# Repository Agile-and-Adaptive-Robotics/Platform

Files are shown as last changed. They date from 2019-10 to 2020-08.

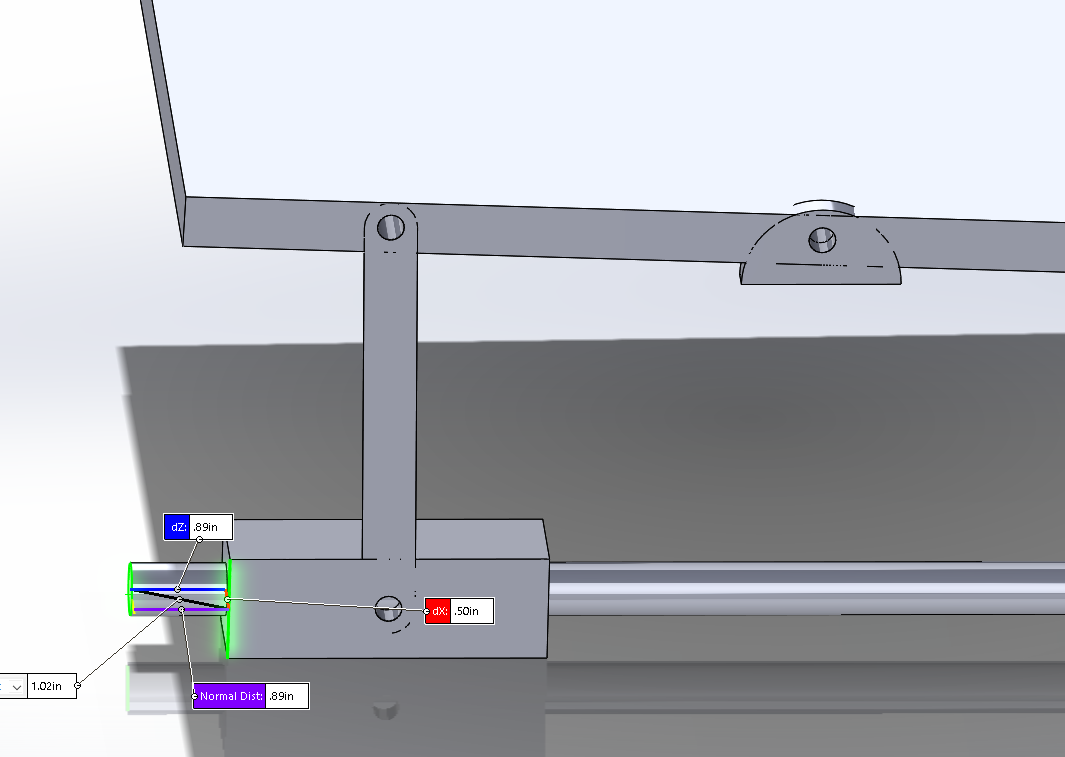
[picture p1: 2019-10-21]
Linsey_s Documentation/screenshots/Works_1redo.PNG

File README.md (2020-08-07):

# Platform

This repo is for the Platform project to test the Bipedal robot in the Agile Adaptive Robotics Lab

Platform

## Content

Goals: To create a balance platform that can vibrate at pseudorandom pattern to test the Bipedal robot. 
Dr. Hunt wants the platform to be able to generate a motion following the pseudo random ternary sequence to test the bipedal robot. When the robot is tested on this platform, the transfer function of the bipedal robot can be derived. 

## Deadline:
At least the end of Spring Term 2020 
Due to the pandemic, this deadline has been missed. Currently, there is no deadline.

## Creators:

Original Designer: Lindsey

2nd Designer: Connor Morrow

3rd Designer: Jake Chung

## Parts List:
- LM 7805C - Voltage regulator 
- LM 348N - Quad op-amp
- MCP 4921 - DAC
- Syren 50 - H-Bridge

## Notes:

Link to the DC motor: https://www.robotmarketplace.com/products/0-e30-150.html

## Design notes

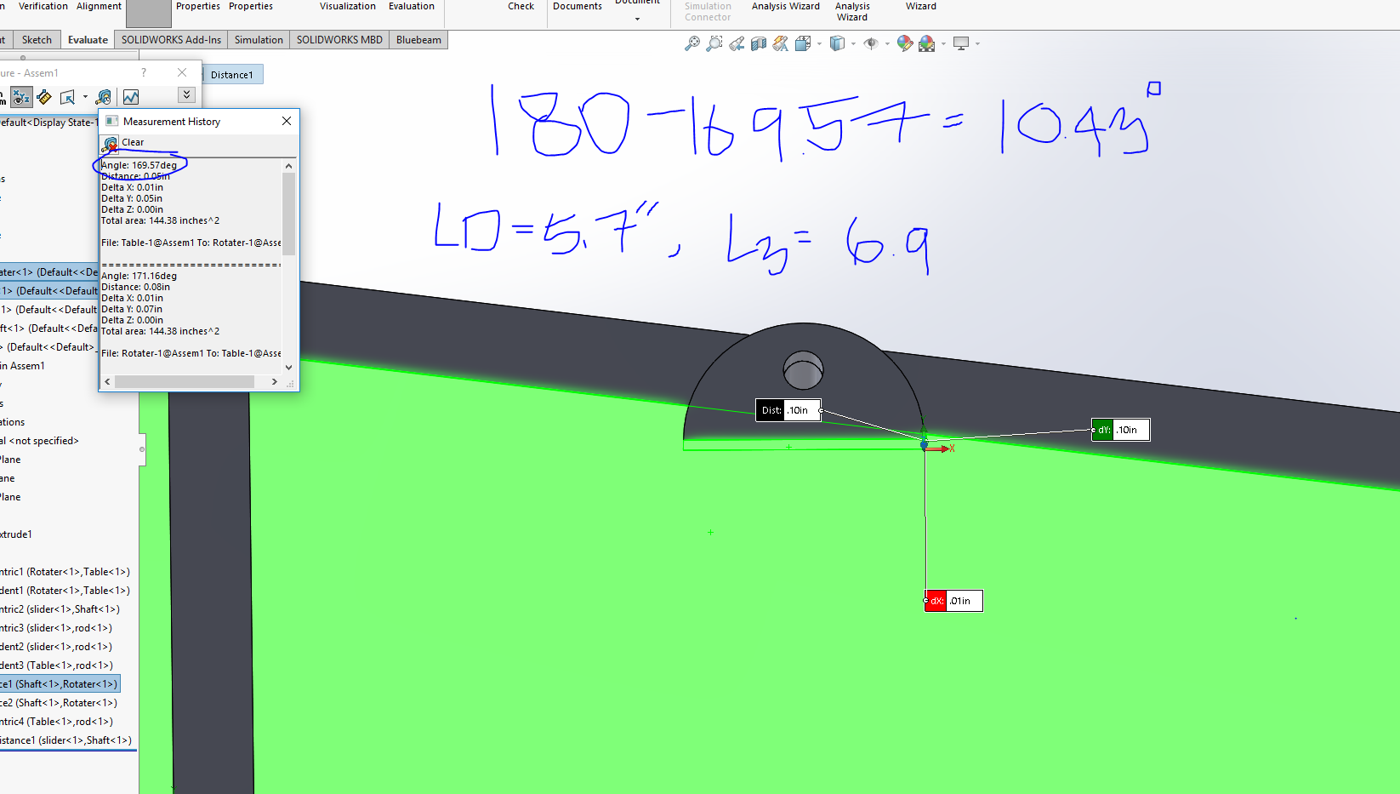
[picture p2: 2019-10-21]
Linsey_s Documentation/screenshots/T3_angle-042218.PNG

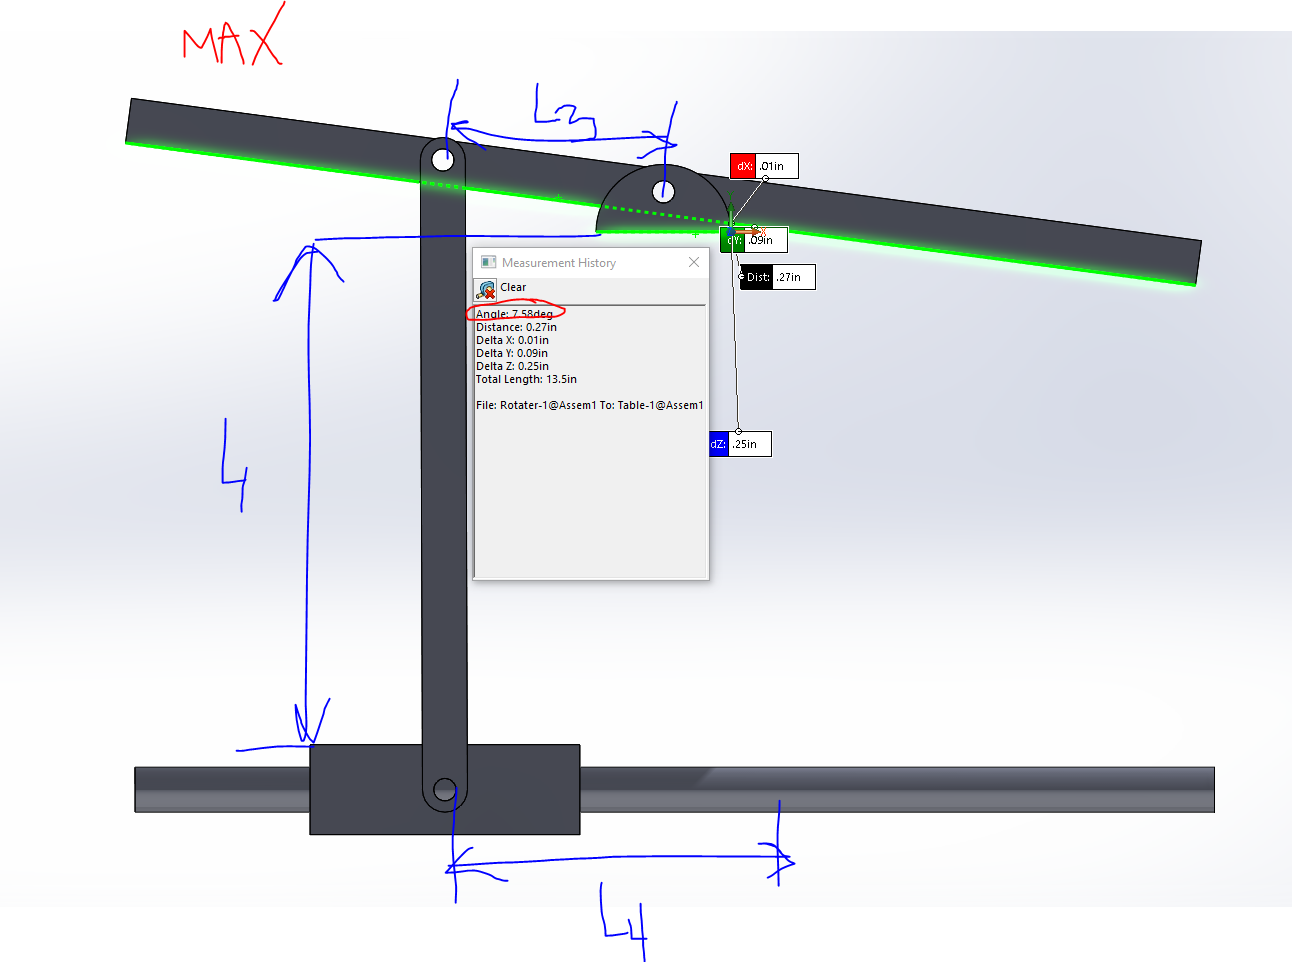
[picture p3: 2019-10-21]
Linsey_s Documentation/screenshots/tech.PNG

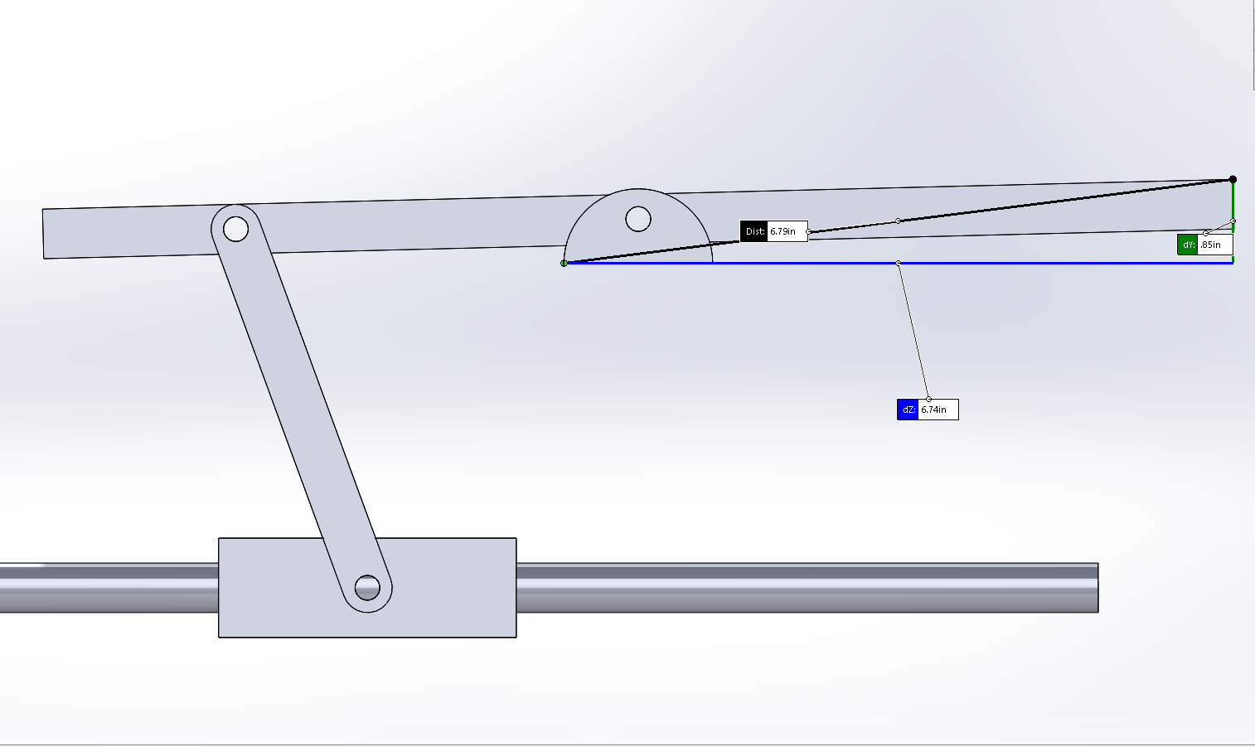
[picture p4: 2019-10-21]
Linsey_s Documentation/screenshots/Works_1_right.PNG

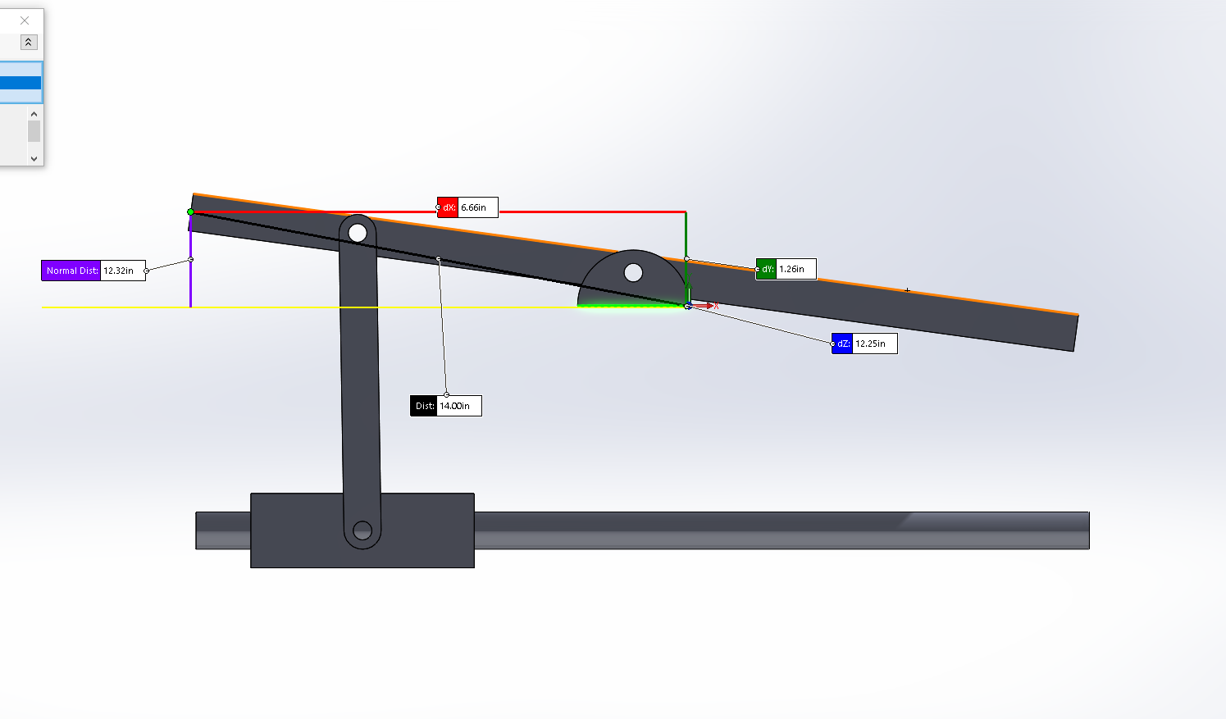
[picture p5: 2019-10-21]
Linsey_s Documentation/screenshots/10 degrees.PNG

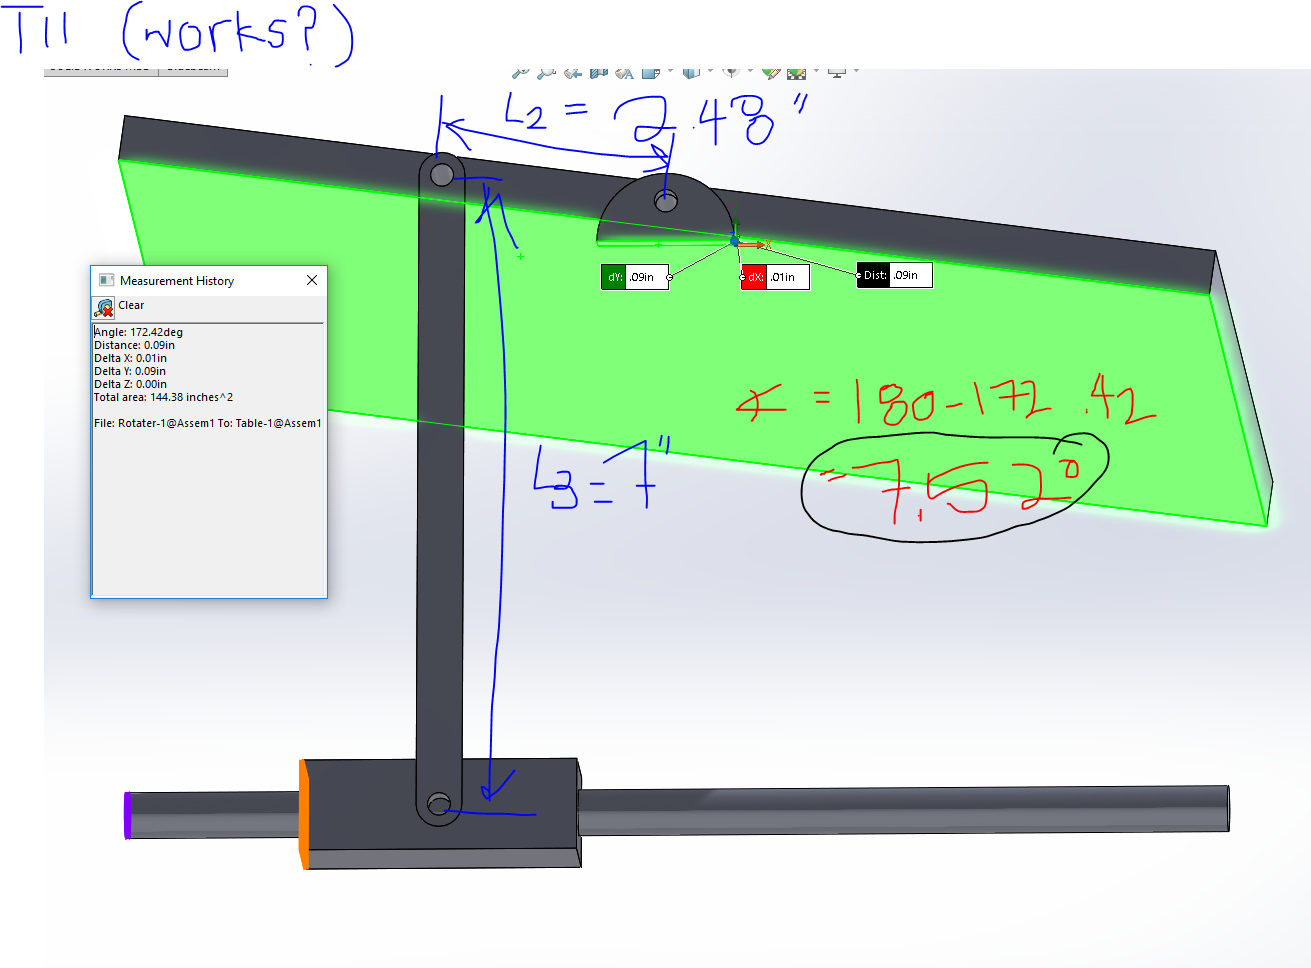
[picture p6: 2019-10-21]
Linsey_s Documentation/screenshots/T11_angle-042418.PNG

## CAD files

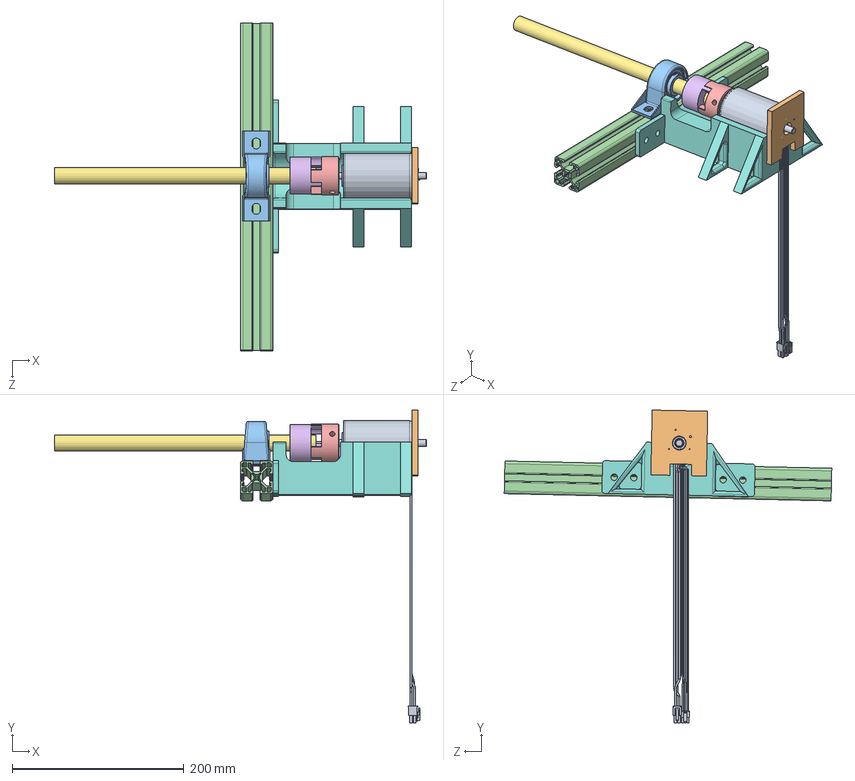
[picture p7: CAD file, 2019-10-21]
Linsey_s Documentation/Solidworks in use/model ideas/mini.SLDASM
433.5 x 364.6 x 381.8 mm
maxon
plate_w_hole
bigrot
8.00004_coup
0.75 coup
no revolve cut shaft
motorsupport

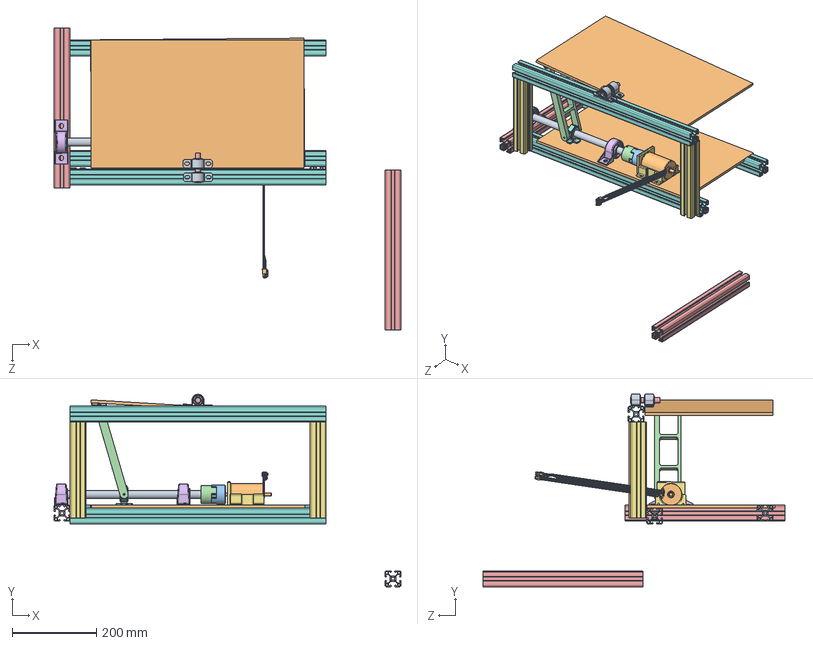
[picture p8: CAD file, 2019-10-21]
Linsey_s Documentation/Solidworks in use/model ideas/PlatBod_other.SLDASM
826.2 x 458.4 x 720.2 mm
rotty x 2
board x 2
tiny_bear x 2
rod2
baby_shaft
bigrot
no revolve cut shaft
maxon
8.005_coup
9939T204_ZERO-BACKLASH FLEXIBLE SHAFT COUPLING
5913K630_LOW-PROFILE MOUNTED BALL BEARING
cradle2
bolt_backpack2
98948A750_GENERAL PURPOSE ACME HEX NUT

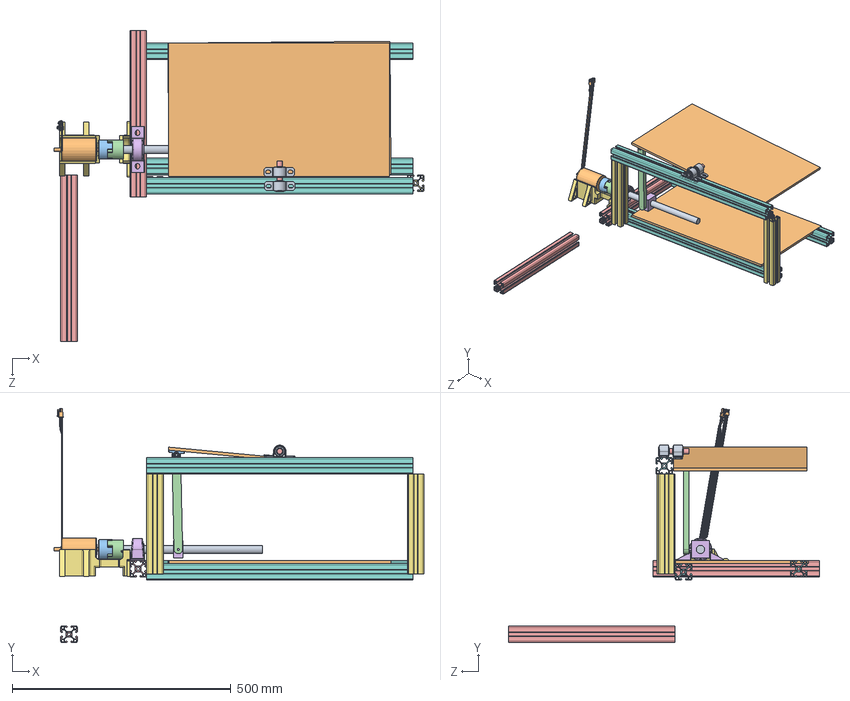
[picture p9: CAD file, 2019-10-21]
Linsey_s Documentation/Solidworks in use/model ideas/PlatBod.SLDASM
846.1 x 535.6 x 711.2 mm
rotty x 2
board x 2
tiny_bear
rod
baby_shaft
bigrot
no revolve cut shaft
maxon
8.005_coup
9939T204_ZERO-BACKLASH FLEXIBLE SHAFT COUPLING
fake_block
motorsupport - Copy2

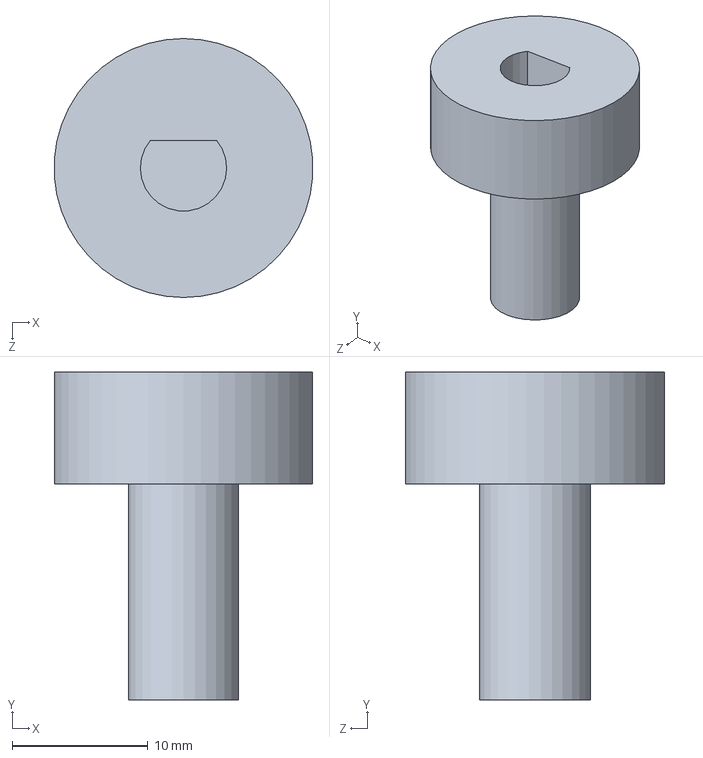
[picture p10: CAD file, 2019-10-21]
Linsey_s Documentation/Solidworks in use/jacks_adaptv2.SLDPRT
19.0 x 24.1 x 19.1 mm

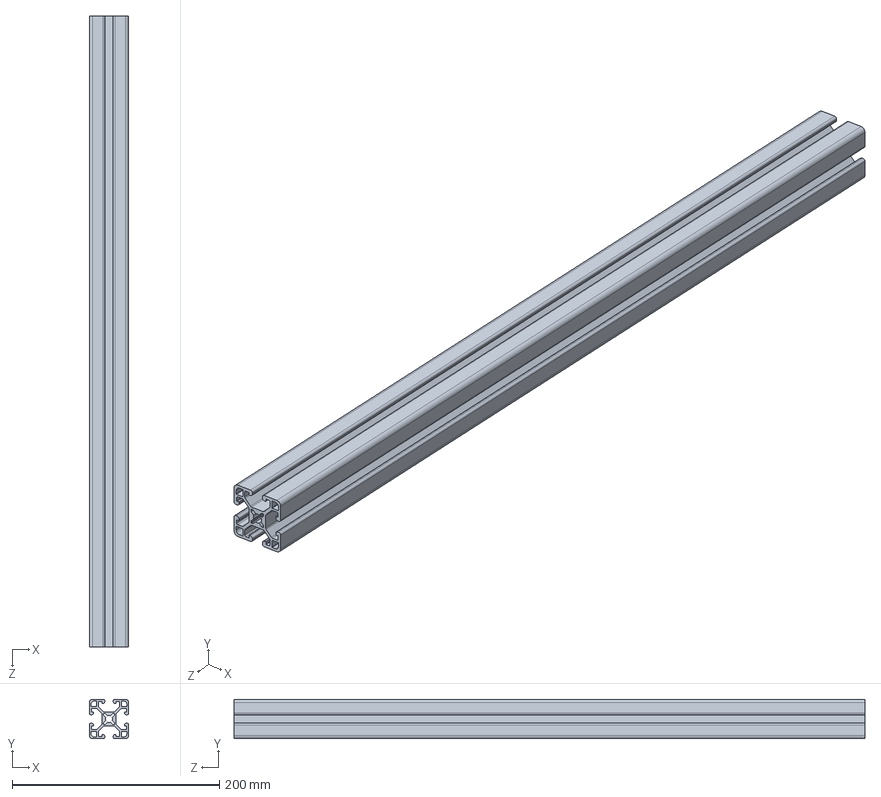
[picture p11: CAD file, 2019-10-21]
Linsey_s Documentation/Solidworks in use/not 3dprinted stuff/1515_24.SLDPRT
38.1 x 38.1 x 609.6 mm

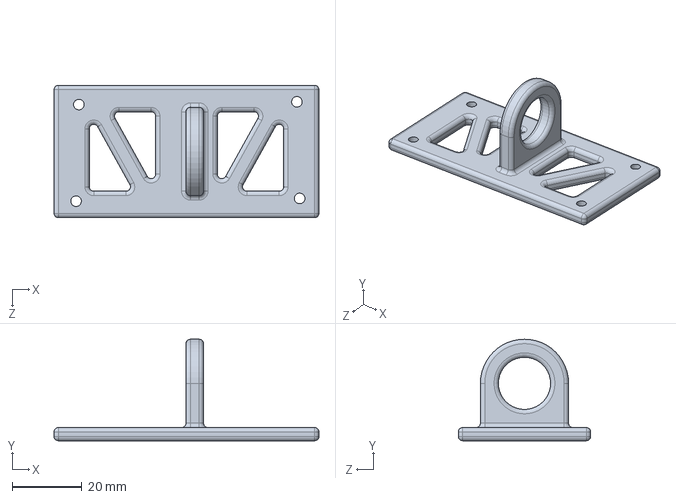
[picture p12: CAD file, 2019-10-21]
Solidworks Files/BP_Platform_Linkage_Connection_1.SLDPRT
76.2 x 29.2 x 38.1 mm

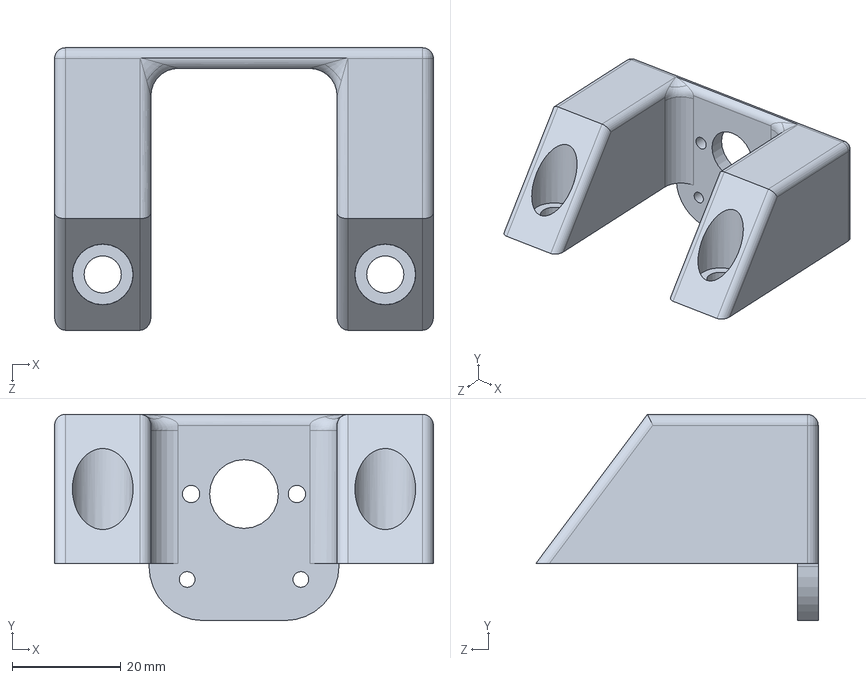
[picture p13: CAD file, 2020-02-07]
Solidworks Files/jakesDesign/BP_encodeHolder.SLDPRT
69.8 x 38.0 x 52.1 mm

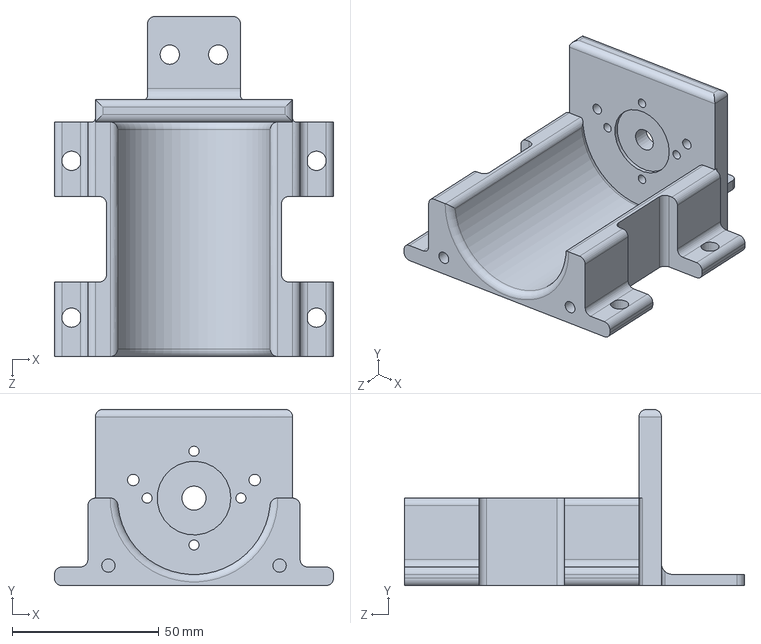
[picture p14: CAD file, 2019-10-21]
Linsey_s Documentation/Solidworks in use/cradle2.SLDPRT
95.2 x 60.1 x 116.0 mm

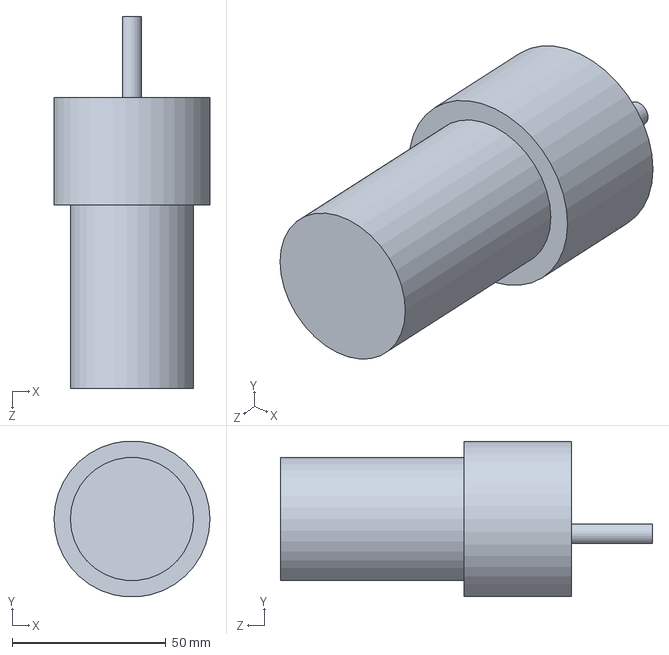
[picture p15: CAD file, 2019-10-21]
Linsey_s Documentation/Solidworks in use/not 3dprinted stuff/mechatronics_motor.SLDPRT
50.8 x 50.6 x 121.2 mm

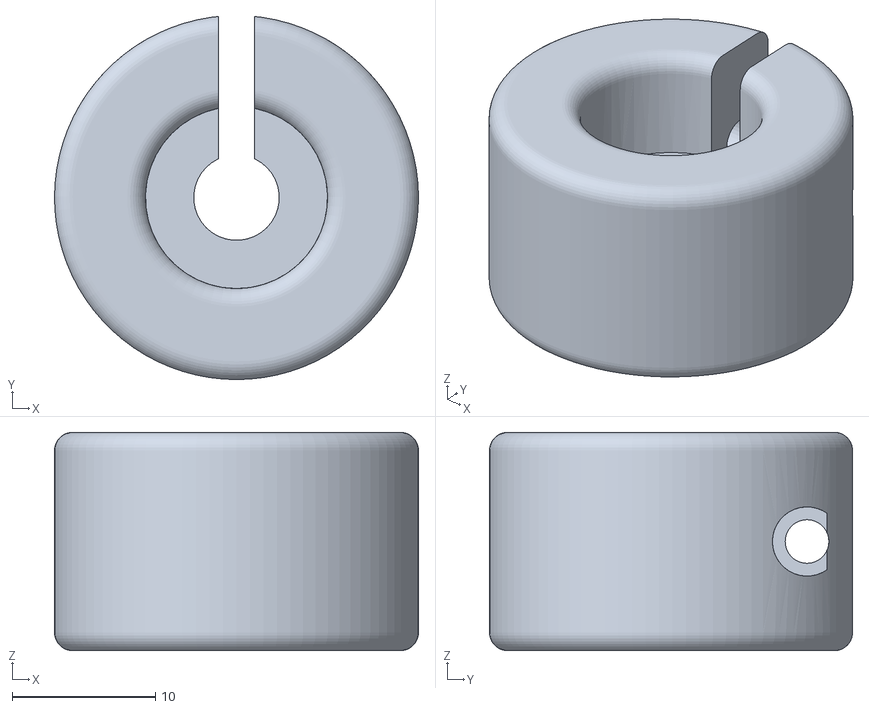
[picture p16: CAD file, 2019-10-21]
Solidworks Files/BP_Pot_Shaft_Interface_2.STL
25.4 x 25.3 x 15.2

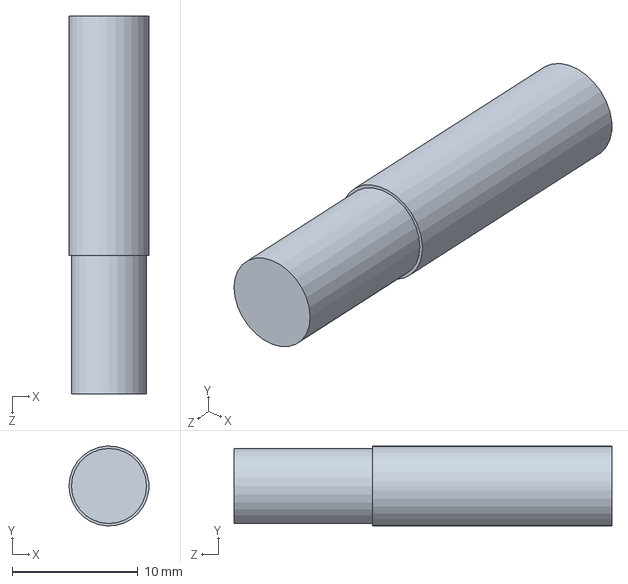
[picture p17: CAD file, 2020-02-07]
Solidworks Files/jakesDesign/encoderShaft.SLDPRT
6.35 x 6.34 x 30.0 mm

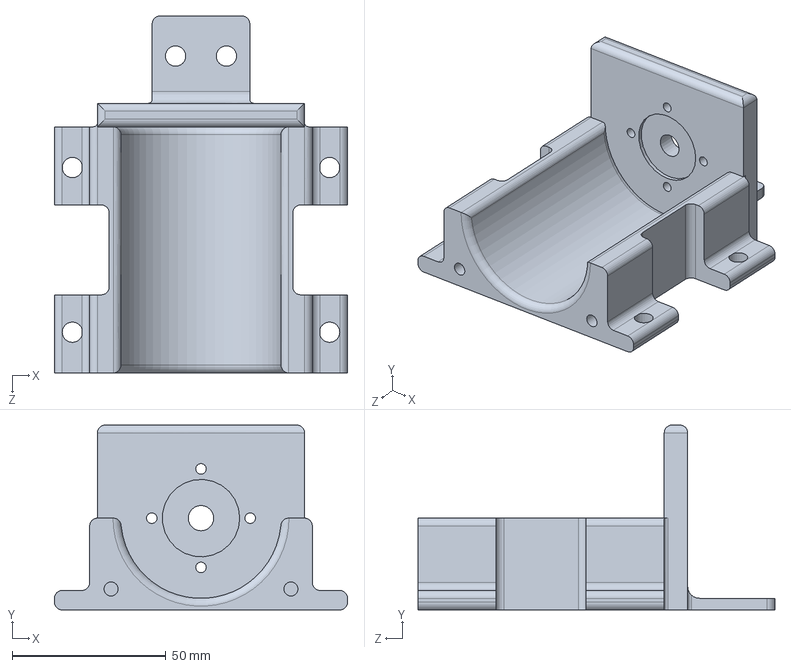
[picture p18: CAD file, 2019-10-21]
Linsey_s Documentation/Solidworks in use/cradle.SLDPRT
95.2 x 60.1 x 116.0 mm

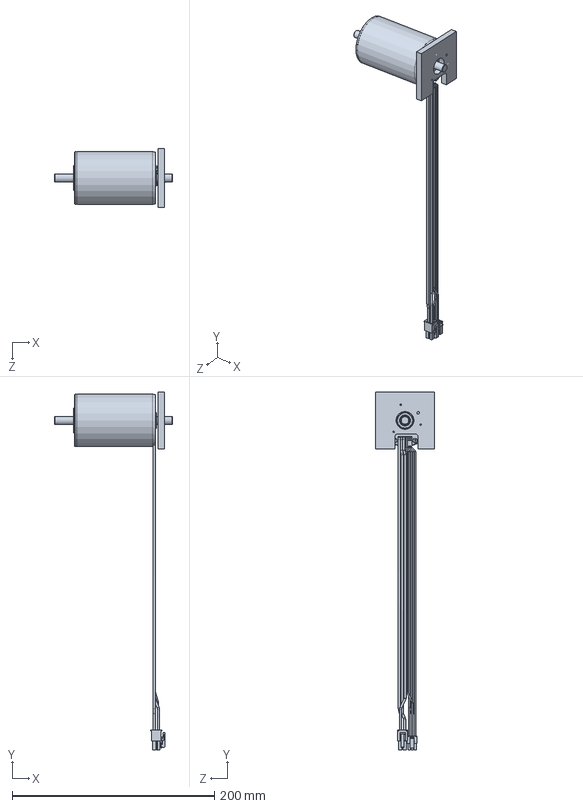
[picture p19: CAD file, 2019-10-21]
Linsey_s Documentation/Solidworks in use/not 3dprinted stuff/maxon - Copy.SLDPRT
116.8 x 354.3 x 58.7 mm

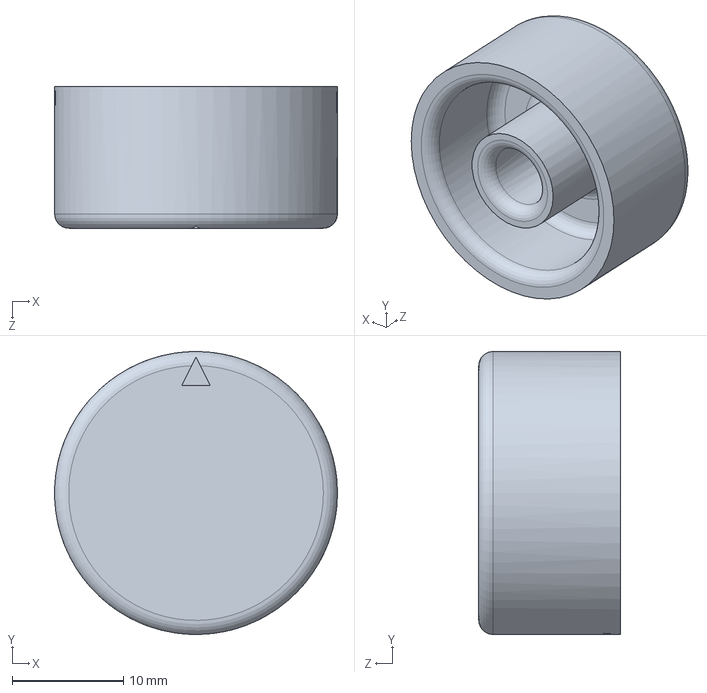
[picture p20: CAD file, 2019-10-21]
Solidworks Files/BP_Potentiometer_Knob_1.SLDPRT
25.4 x 25.4 x 12.7 mm

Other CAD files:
Solidworks Files/jakesDesign/userInterfaceMounting.SLDPRT
Linsey_s Documentation/Solidworks in use/not 3dprinted stuff/1515_9.SLDPRT
Solidworks Files/jakesDesign/encoderShaftPlatformInterface.SLDPRT
Linsey_s Documentation/Solidworks in use/jacks_adaptv3.SLDPRT
Linsey_s Documentation/Solidworks in use/Spider - fixed by cody.SLDPRT
Linsey_s Documentation/Solidworks in use/bolt_backpack2.SLDPRT
Linsey_s Documentation/Solidworks in use/insert.SLDPRT
Linsey_s Documentation/Solidworks in use/jacks_coupler.SLDPRT
Linsey_s Documentation/Solidworks in use/not 3dprinted stuff/1515_15.SLDPRT
Linsey_s Documentation/Solidworks in use/not 3dprinted stuff/bigrot.SLDPRT
Linsey_s Documentation/Solidworks in use/not 3dprinted stuff/rotty.SLDPRT
Linsey_s Documentation/Solidworks in use/not 3dprinted stuff/tiny_bear.SLDPRT
Linsey_s Documentation/Solidworks in use/simp_coup.SLDPRT
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

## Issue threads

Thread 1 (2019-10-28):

Touching the Mega during operation causes the system to go crazy

jakechung42, 2019-10-28:
For some reason, during operation, if you touch the Mega, the platform will go either all forwards or backward. Might need to switch out for another Mega or change to Mega to a Due

jakechung42, 2019-11-15:
Replacing and new Arduino Mega doesn't fix the noise issue. Next step is to try to replace the jumper cables with better cables.

jakechung42, 2019-11-15:
found the problem: it's the voltage input to the Mega that has been causing the noise.

Closed 2019-11-15.

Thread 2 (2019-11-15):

Derive the transfer function of the system

jakechung42, 2019-11-15:
To design the control system, the transfer function has to be derived first.

jakechung42, 2019-12-16:
Going to derive the transfer function using Bode method. Although the encoder feature is currently being worked on first. When the system is stable, going to start collecting frequeny response.

jakechung42, 2020-02-07:
can just generate the sine function digitally in the Mega and collect the response.

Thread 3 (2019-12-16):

Encoder drift

jakechung42, 2019-12-16:
the 0 position of the encoder drifts significantly when the platform oscillate at high frequency. Going to try out several different methods to fix.

jakechung42, 2019-12-16:
using the encoder Arduino library, they recommend using Arduino Mega interupt pins. Tried that and it seems to be better. Going to test more.

jakechung42, 2019-12-16:
Using the interupt pins on the Arduino now. The drifting seems to be solved. Move on.

Closed 2019-12-16.

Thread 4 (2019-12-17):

The buffer circuit is messing up everything

jakechung42, 2019-12-17:
Without the negative voltage, the buffer and filter circuit doesn't function properly. The signal output of the DAC calls for a minimum voltage of 1.24V but the minimum that the buffer circuit can provide (when the negative power supply is hooked up to ground) 1.8V. The sine wave input is cut off at 1.8V. Potential solution is to provide a negative rail to the buffer circuit for get rid of it completely.

jakechung42, 2020-02-07:
Just have to keep in mind that op amp needs power from -15 to +15V. Since the circuit is only from 0 to 15V, there are weird behavirors in more complex op amp circuits. Close issue for now but will reopen if nessesary.

Closed 2020-02-07.

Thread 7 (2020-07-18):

Everything goes back to the op amp not being supplied with a positive and negative voltage

jakechung42, 2020-07-18:
The op-amp is being supplied by 5V and 0V. This limits the output range of the op-amp and truncates the output voltage. In this configuration at 5V and 0V input, the op-amp caps at 1.91V - 4.25V.

jakechung42, 2020-09-05:
this problem is fixed temporarily for now. Hooked up a power supply to the circuit to provide a negative rail.

Closed 2020-09-05.

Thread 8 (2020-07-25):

Drift of the 0 degree position.

jakechung42, 2020-07-25:
During data collection, the zero degree position drifts. It doesn't even start out in the correct position.
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

Don't know what is causing this issue yet, maybe mechanical or electrical.
Mechanical: it seems like the axial connecting the top plate and the arm is not very tight and can be seeem to come loose during test runs.
Electrical: the output of the DAC and the buffer/filter is not perfectly 2.5V. Misc resistances in the circuit might not be producing the correct desired voltage.

jakechung42, 2020-07-31:
check hysteresis affect.

jakechung42, 2020-08-05:
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
The interrupt in the Encoder sampling is messing up the timer interrupt routine in the sine wave generation code. The figure shows the input sinusoidal position of 2 trials: one with the encoder sampling and one with the encoder off. The sampling of the encoder seems to trigger an interrupt that messes with the timer interrupt, which causes the input sinusoidal position to be behaving not as desired.

jakechung42, 2020-08-07:
The problem is because I have been writing out the control signal rather than the desired postion signal.

jakechung42, 2020-09-12:
this might be due to the physical connection between the moment arm and the top plate. Redesigning a more rigid connection.

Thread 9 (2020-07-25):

The position read by the encoder is relative.

jakechung42, 2020-07-25:
The reading of the encoder is relative. By saying this, I mean that the encoder stores the pulses in its object to count the angle. If the object is reset by means of resetting the code or resetting the power, it will begin to count again from 0.  This causes the actual angle of the top plate to be not the same as the reading of the encoder. An idea is to mount an IMU to the platform and create a routine to calibrate the platform.

jakechung42, 2020-07-31:
Using an IMU wouldn't work either because IMU position is also relative. I think the best way to do it is to use a potentiometer for calibration but using an encoder for sensory measurement in the feedback loop. Initially, the pot wasn't desirable because the voltage range is only 5V so the pot resolution wasn't really good and I didn't want to change the operating voltage, so I went with the encoder. Using the pot for the calibration shouldn't introduce the resolution problem again.

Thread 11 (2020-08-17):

Design a better connector piece that connects the moment arm and the top flat plate.

jakechung42, 2020-08-17:
The current connection between the top plate and the moment arm is not very rigid. When the plate oscillatess at high frequency (~1Hz), the bearing and shaft come loose.

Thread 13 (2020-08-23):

The encoder is not working

jakechung42, 2020-08-23:
The encoder does not send out signals to the Mega. Probably will need to replace it with a new one. I might have broken it when I worked on it 2 weeks ago. This could be the reason why the platform has been having open-loop behavior.

jakechung42, 2020-09-05:
fixed it. The encoder physically is fine, it's just that there was some type conversion error in the code.

Closed 2020-09-05.

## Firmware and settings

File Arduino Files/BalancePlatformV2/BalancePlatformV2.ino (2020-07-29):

/* Balance Platform Code
 *  Connor Morrow
 *  8/26/2019
 *  
 *  This code is used to control the balance platform used for determining balance characteristics of robots.
 *  The code holds its output at a constant 2.5V (the voltage for no motor velocity), until it detects a high signal coming from the H-Bridge.
 *  When the high signal is recieved, the Arduino switches to producing a sine wave output. 
 *	
 *	Jake Chung
 *	12/20/2019
 *	Update Connor's code to use encoder to measure the angle of the platform.
 */
/*----------------------- Included Libraries  --------------------------------*/
#include <SPI.h>          //For communicating with DAC
#include <Encoder.h>	

//Dac Library information at http://arduino.alhin.de/index.php?n=8
#include <AH_MCP4921.h>   //For easy DAC functions

//Define encoder pins. Encoder pins have to be interupt pins
#define encA 19
#define encB 20

/*----------------------- Definitions  --------------------------------*/
AH_MCP4921 AnalogOutput(51, 52, 53);          //SPI communication is on Arduino MEGA Pins 51, 52, 53


/*----------------------- Pin Declarations --------------------------------*/
int InputPin = A0;                      //Pin that takes in values from a function generator or potentiometer
    
volatile uint8_t VoltageMode = 0;		//Variable that keeps track of voltage mode, 0 for hold, 1 for manual control, 2 for PRTS

uint8_t HoldPin = 2;                    //Pin connected to a button that switches voltage from 2.5V to variable   
uint8_t HoldLED = 7;                    //Pin connected to an LED that is dim when voltage supplied to the Hbridge is 2.5V and lit when the voltage is variable

uint8_t ManualControlPin = 18;           //Pin connected to a button that switches control voltage to be based on the position of a manually controlled potentiometer
uint8_t ManualControlLED = 6;           //Pin connected to an LED that is lit when the platform is in manual control

uint8_t PRTSPin = 3;                    //Pin connected to a button that switches control voltage to be generated by the PRTS
uint8_t PRTSLED = 9;                    //Pin connected to an LED that is lit when the platform is controlled by PRTS signal

/*------------------------ Control Parameters -----------------------------*/
float KP = 1.0;
int DACoffset = 4096.0/2.0;
int SetPoint = 366.0;


/*------------------------PRTS Parameters ---------------------------------*/
float PRTSAngle = 0.0;
float VelocityGain = 0.3;
int counter = 0;
boolean test = 0;

//Encoder set up
Encoder myEnc(encA, encB);

void setup() {
  //Serial.begin(9600);
  pinMode(InputPin, INPUT);
  pinMode(HoldPin, INPUT);
  pinMode(HoldLED, OUTPUT);
  pinMode(ManualControlPin, INPUT);
  pinMode(ManualControlLED, OUTPUT);
  pinMode(PRTSPin, INPUT);
  pinMode(PRTSLED, OUTPUT);
  attachInterrupt(digitalPinToInterrupt(HoldPin), HoldVoltage, CHANGE);
  attachInterrupt(digitalPinToInterrupt(ManualControlPin), ManualVoltage, CHANGE);
  attachInterrupt(digitalPinToInterrupt(PRTSPin), PRTSVoltage, CHANGE);
  
  //Set PWM on pin 8 to have a frequency of 4kHz
  int prescaler = 2;
  int myEraser = 7;
  TCCR4B &= ~myEraser;         //Erases the last three bits of the register so that we can replace them with our scaler
  TCCR4B |= 2;                 //Sets timer 4 PWM frequency to 4kHz

  InterruptSetup(); 
}

void loop() {
  if(VoltageMode == 0){
    digitalWrite(HoldLED, HIGH);
    digitalWrite(ManualControlLED, LOW);
    digitalWrite(PRTSLED, LOW);
  }
  else if(VoltageMode == 1){
    digitalWrite(HoldLED, LOW);  
    digitalWrite(ManualControlLED, HIGH);
    digitalWrite(PRTSLED, LOW);
  }
  else if(VoltageMode == 2){
    digitalWrite(HoldLED, LOW);  
    digitalWrite(ManualControlLED, LOW);
    digitalWrite(PRTSLED, HIGH);
  }
}

void HoldVoltage(){
  VoltageMode = 0;
}

void ManualVoltage(){
  VoltageMode = 1;
}

void PRTSVoltage(){
  VoltageMode = 2;
}

void InterruptSetup(){
  cli();//stop interrupts
  
  //set timer0 interrupt at 50 Hz
  TCCR1A = 0;// set entire TCCR1A register to 0
  TCCR1B = 0;// same for TCCR1B
  TCNT1  = 0;//initialize counter value to 0
  // set compare match register for 1hz increments
  OCR1A = 1249;// = (16*10^6) / (1*1024) - 1 (must be <65536)
  // turn on CTC mode
  TCCR1B |= (1 << WGM12);
  // Set CS10, CS11, and CS12 bits for 256 prescaler
  TCCR1B |= (1 << CS12) | (0 << CS11) | (0 << CS10);  
  // enable timer compare interrupt
  TIMSK1 |= (1 << OCIE1A);

  sei();//allow interrupts
}

ISR(TIMER1_COMPA_vect){
  if(VoltageMode == 0){
	  AnalogOutput.setValue(4096/2);
  }
  else if(VoltageMode == 1){
		//Read the encoder
	  float pos = myEnc.read();
	  float encAngle = 10.0/226.0*pos;
	  
	  float PosValue = analogRead(InputPin);                            //Reads position value from a manually controller potentiometer
	  float PosAngle = 10.0/256.0*PosValue - 20.0;
    
	  float error = encAngle - PosAngle;                               //Value - setpoint, so that the correct motor polarity is achieved
	  float DACerror = error*4096.0/20.0;
	  float DACsignal = KP*DACerror + DACoffset;              // I think the increased polarity only happens when the arduino is plugged into the computer.
    if(DACsignal > 4095.0){
      DACsignal = 4095.0;
    }
    else if(DACsignal < 0.0){
      DACsignal = 0.0;
    }
    AnalogOutput.setValue((int) DACsignal);
    //Serial.print("Position Voltage:  "); Serial.print(PosValue); Serial.print("  Pos Angle:  "); Serial.print(PosAngle); Serial.print("   Potentiometer Reading:  "); Serial.print(PotValue); Serial.print("  Potentiometer Angle:  "); Serial.print(PotAngle); Serial.print("  Error:  "); Serial.print(error); Serial.print("    DAC Signal:  "); Serial.println(DACsignal);
    }
    else if(VoltageMode == 2){

    /* PRTS Control */
    //Example code first
    float pos = myEnc.read();
    float encAngle = 10.0/226.0*pos;
    //Test code generating a triangle wave
    
    //Calculate current time in the period of the triangle wave
    counter += 1;
    if(counter == 501){
      counter = 1;
    }

    //Calculate output 
    if(counter <= 125){
      PRTSAngle = 5.0/125.0*((float) counter);
    }
    else if(counter <= 375){
      PRTSAngle = 5.0-10.0/250.0*((float) counter - 125.0);
    }
    else if(counter <= 500){
      PRTSAngle = -5+5.0/125.0*((float) counter - 375.0);
    }
    else {
      PRTSAngle = 0.0;
    }

    float error = pos - PRTSAngle;                               //Value - setpoint, so that the correct motor polarity is achieved
    float DACerror = error*4096.0/20.0;
    float DACsignal = KP*DACerror + DACoffset;              // I think the increased polarity only happens when the arduino is plugged into the computer.
    if(DACsignal > 4095.0){
      DACsignal = 4095.0;
    }
    else if(DACsignal < 0.0){
      DACsignal = 0.0;
    }
    AnalogOutput.setValue((int) DACsignal);
  }
}

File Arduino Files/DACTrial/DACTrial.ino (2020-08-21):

#include <SPI.h>
#include <AH_MCP4921.h>
#include <Encoder.h>      //For encoder 

//define the encoder pins
#define encA 19
#define encB 20

//Encoder set up
Encoder myEnc(encA, encB);

//DAC set up
AH_MCP4921 AnalogOutput(51, 52, 53);

//declare variables
float desirePos = 2048; //position set by the serial port
int pos = 0; //position read by the encoder
String readStr;
float readVoltage;
float err;
float DACinput;


void setup() {
  Serial.begin(115200);
  delay(200); //need this delay to set the value of the DAC
  AnalogOutput.setValue(pos); //initiate at the 0 position.
}

void loop() {
  if(Serial.available()){ //wait for serial to read
    readStr = Serial.readString(); //use readString to read the entire number
    desirePos = readStr.toInt(); //convert string to integer
    desirePos = 2.5/2048*desirePos;
  }
  //apply negative feedback 
  pos = myEnc.read();
  readVoltage = 0.25*(pos*0.17578)+2.5; //convert encoder pulses to voltage
  err = desirePos - readVoltage; //calculate error
  float DACVoltage = err + 2.5; //offset the error
  DACinput = 2048/2.5*DACVoltage; 
  AnalogOutput.setValue((int) DACinput);
  
  /*
  for(int i = 1000; i <= 3095; i=i+10){
    AnalogOutput.setValue(i);
    delay(1);
  }
  */
  /*
  while(1){
    int currentTime = millis();
    int pos = currentTime%Period;
    float BalanceSignal = amp*sin(freq*pos)+offset;
    //int OutputSignal = map(BalanceSignal, 0, 5, 0, 4095);
    int OutputSignal = BalanceSignal*(4095/5);
    //Serial.print(BalanceSignal); Serial.print("       "); Serial.println(OutputSignal);
    AnalogOutput.setValue(OutputSignal);
    delay(10);
  }
  */
  
  
}

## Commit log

2019-10-21 update link to the DC motor
2019-10-21 update repo with files from the Google Drive
    [12in_shaft.SLDPRT, 1515_15.SLDPRT, 1515_24.SLDPRT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]
2019-12-12 datasheet of the encoder
2019-12-13 new design for the encoder holder
    [BP_encodeHolder.SLDPRT]
2019-12-13 shaft connecting encoder to the platform
    [encoderShaft.SLDPRT]
2019-12-16 working on a new algorithm for the BP using encoder
2019-12-16 test encoder control algorithm
2019-12-16 change dimensions
    [encoderShaft.SLDPRT]
2019-12-17 working code for the platform using encoder
2020-02-07 move the main Arduino file into its own folder.
2020-07-08 this is not simple. The analog pin doesn't write true analog values, but it writes voltage value in term of PWM signal. I don't think I can construct a signwave from PWM signal.
    [testSineWaveGen.ino]
2020-07-09 data for the sinewave generation
    [acq0001.csv]
2020-07-17 change variable definition of interrupt pin to add volatile
2020-07-18 this code generate the sine wave pattern at different frequency and collect data from the encoder
2020-07-18 Revert "this code generate the sine wave pattern at different frequency and collect data from the encoder"
    This reverts commit 1b2c15d78fe10acb4249f69cb1b99a0851ec8ab3.
2020-07-21 adding board type comment
2020-07-21 adding function to print the data to serial for MATLAB to collect
2020-07-21 the code somehow broke
    [SineGenerationTrial.ino]
2020-07-23 adding a break between frequencies seems to cause issue in the serial write process. Comment this out for now to investigate the problem.
    [SineGenerationTrial.ino]
2020-07-23 move the frequency increment inside the interrupt
2020-07-24 add volatile varriables for consistency of the interrupt
2020-07-24 first attempt to write the sine wave generation program on a Arduino Due (this does not work)
    [SineWaveGeneration.ino]
2020-07-25 remove print out to terminal
2020-07-29 initial commit to test the IMU
2020-08-05 move the rawData folder into the data Analysis folder for easy call in Matlab
    [acq0001.csv]
2020-08-07 This is an important error. I have been writing the control signal out to the serial port, but what I should have been writing out is the desired postion data.
    [SineGenerationTrial.ino]
2020-08-08 change conversion contant from the encoder to voltage
2020-08-21 sine generation in reverse order from high freq to low freq
    [SineGen_reverseOrder.ino]
2020-08-22 these conversion should output the correct values to the DAC. Will test when get to the lab
    [SineGenerationTrial.ino]
2020-08-22 add the changes also to the reverse order sine generation
    [SineGen_reverseOrder.ino]
2020-08-22 change the conversion in error computation
    [SineGenerationTrial.ino]
2020-08-23 this is now a stable version. Fixed the issue with encoder not reading and open loop behavior
    [SineGenerationTrial.ino]
2024-06-04 test part
    [Part1.SLDPRT]
2024-06-04 Deleted test part
    [Part1.SLDPRT]
